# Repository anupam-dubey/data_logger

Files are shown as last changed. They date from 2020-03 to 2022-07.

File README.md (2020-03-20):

##  Data Logger with SD card and CSV Export    
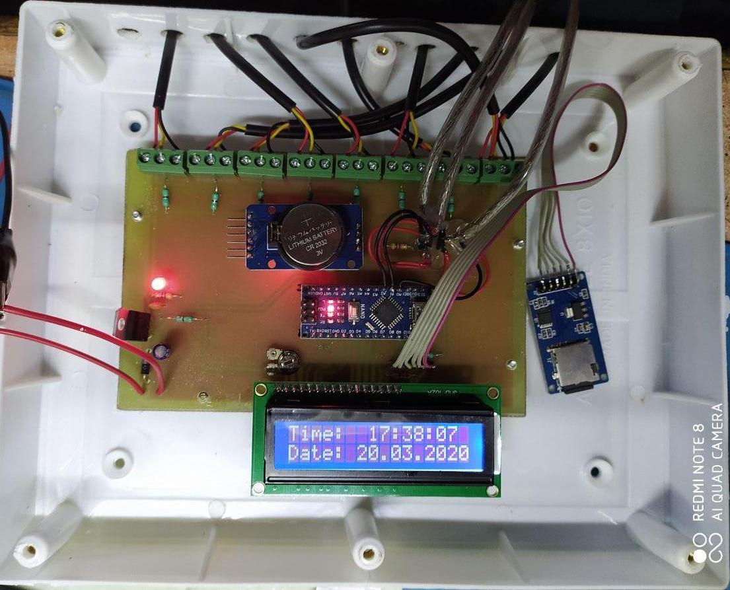
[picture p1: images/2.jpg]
           
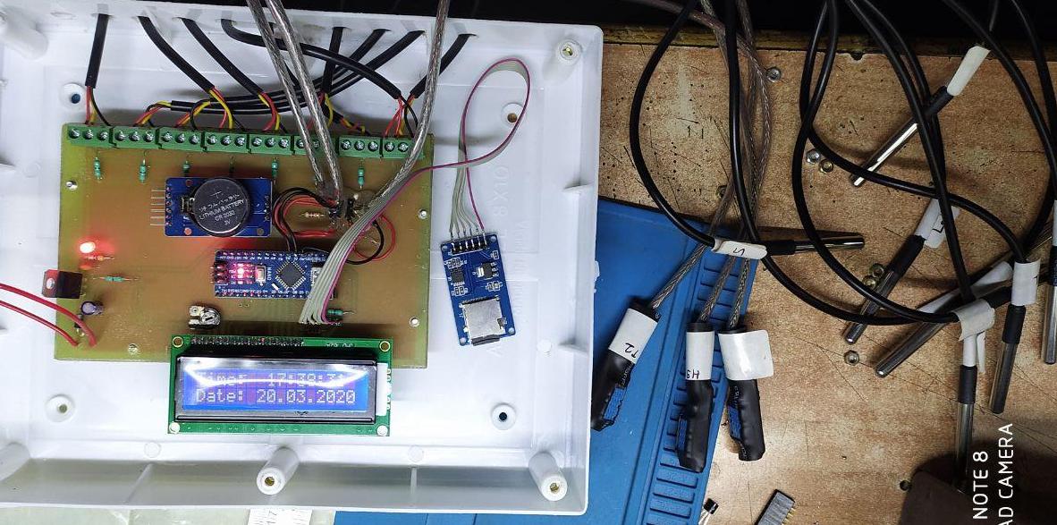
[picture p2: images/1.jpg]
     

#### Project reads data from 9 DS18b20 sensors   
#### alongwith 3 DHT11 sensor for 12 temperature readouts   
### HARDWARE   
Arduino nano ds3231 rtc module sd card module
Arduino ide is used with 16gb fat32 sd card  
project completed on 20/3/2020

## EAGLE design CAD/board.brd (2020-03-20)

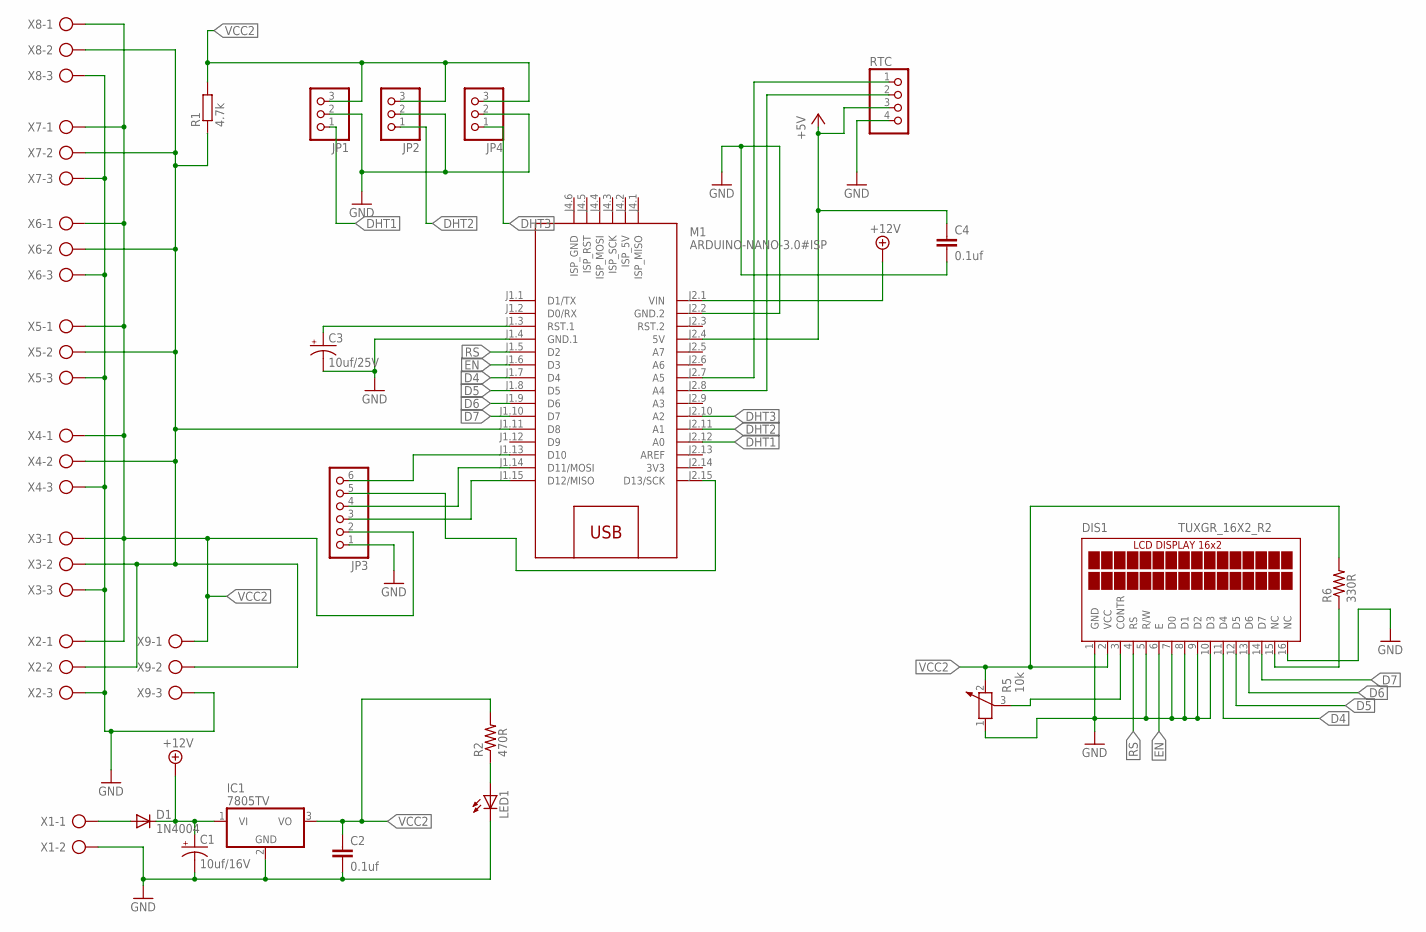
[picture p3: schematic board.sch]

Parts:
C1: 10uf/16V; E2,5-5
C2, C4: 0.1uf; C050-035X075
C3: 10uf/25V; E2,5-5
D1: 1N4004; DO41-10
DIS1: TUXGR_16X2_R2
IC1: 7805TV; TO220V
JP1, JP2, JP4: PINHD-1X3; 1X03
JP3: PINHD-1X6; 1X06
LED1: LED3MM
M1: ARDUINO-NANO-3.0#ISP
R1: 4.7k; 0207/10
R2: 470R; 0207/10@1
R5: 10k; PT-10
R6: 330R; 0207/10@1
RTC: PINHD-1X4; 1X04
X1: AK500/2
X2, X3, X4, X5, X6, X7, X8, X9: AK500/3

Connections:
3V3: M1.J2.14 (3V3)
+5V: C4.1, M1.J2.4 (5V), RTC.3
+12V: C1.+, D1.C, IC1.1 (VI), M1.J2.1 (VIN)
D4: DIS1.11 (D4), M1.J1.7 (D4)
D5: DIS1.12 (D5), M1.J1.8 (D5)
D6: DIS1.13 (D6), M1.J1.9 (D6)
D7: DIS1.14 (D7), M1.J1.10 (D7)
DHT1: JP1.1, M1.J2.12 (A0)
DHT2: JP2.1, M1.J2.11 (A1)
DHT3: JP4.1, M1.J2.10 (A2)
EN: DIS1.6 (E), M1.J1.6 (D3)
GND: C1.-, C2.2, C3.-, C4.2, DIS1.1 (GND), DIS1.5 (R/W), DIS1.7 (D0), DIS1.8 (D1), DIS1.9 (D2), DIS1.10 (D3), DIS1.16 (NC), IC1.2 (GND), JP1.2, JP2.2, JP3.1, JP4.2, LED1.K (C), M1.J1.4 (GND.1), M1.J2.2 (GND.2), R5.1, RTC.4, X1.2, X2.3, X3.3, X4.3, X5.3, X6.3, X7.3, X8.3, X9.3
unnamed: D1.A, X1.1
unnamed: C3.+, M1.J1.3 (RST.1)
unnamed: JP1.3, JP2.3, JP4.3, R1.2
unnamed: M1.J2.7 (A5), RTC.1
unnamed: M1.J2.8 (A4), RTC.2
unnamed: M1.J1.11 (D8), R1.1, X2.2, X3.2, X4.2, X5.2, X6.2, X7.2, X8.2, X9.2
unnamed: DIS1.3 (CONTR), R5.3
unnamed: DIS1.15 (NC), R6.1
unnamed: JP3.3, M1.J1.15 (D12/MISO)
unnamed: JP3.4, M1.J1.14 (D11/MOSI)
unnamed: JP3.5, M1.J2.15 (D13/SCK)
unnamed: JP3.6, M1.J1.13 (D10)
unnamed: LED1.A, R2.1
RS: DIS1.4 (RS), M1.J1.5 (D2)
VCC2: C2.1, DIS1.2 (VCC), IC1.3 (VO), JP3.2, R2.2, R5.2, R6.2, X2.1, X3.1, X4.1, X5.1, X6.1, X7.1, X8.1, X9.1

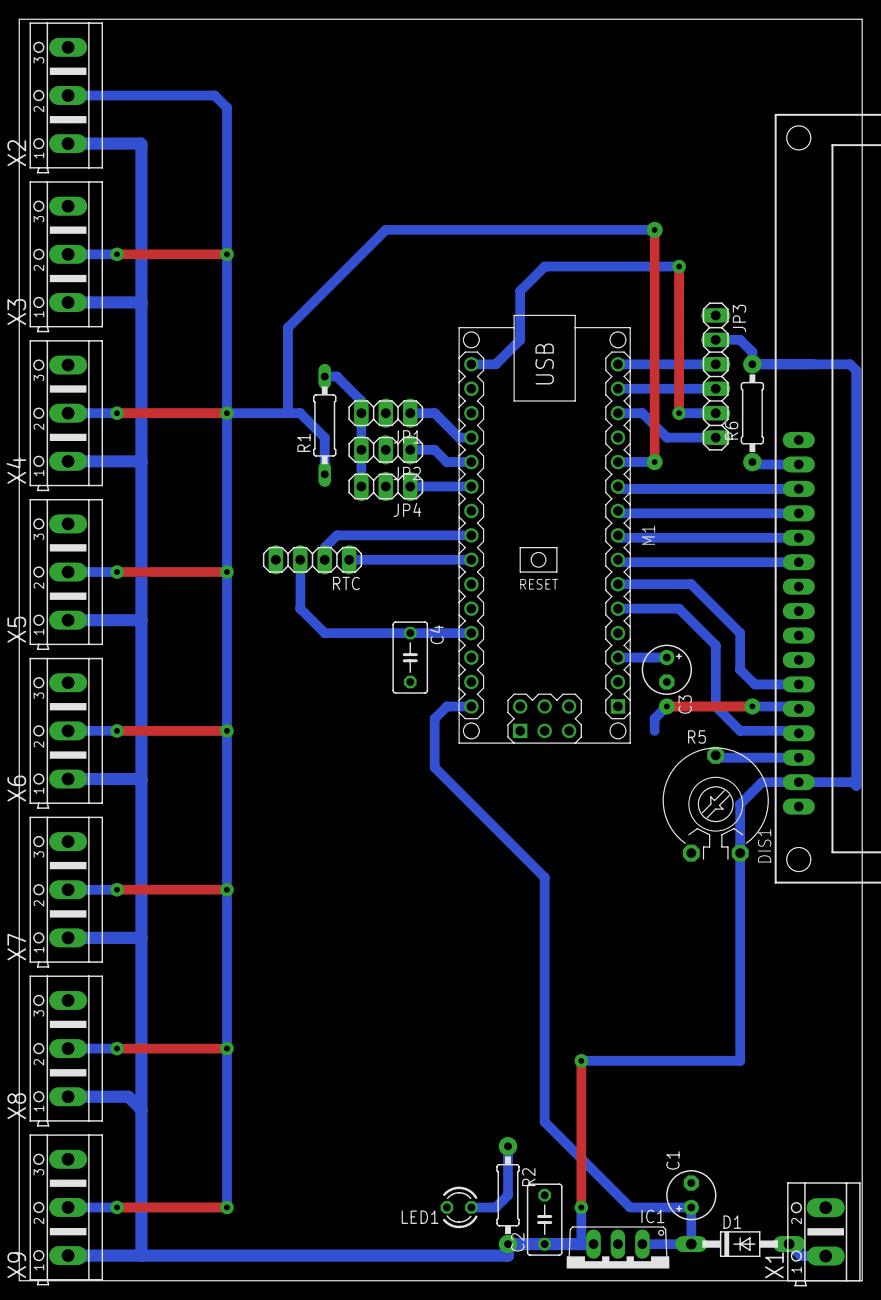
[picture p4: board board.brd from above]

Board: 2 copper layers, 87.6 x 131.1 mm, 27 parts (0 on the bottom side), 26 nets.

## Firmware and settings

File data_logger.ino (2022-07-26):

// just for ketan
#include <SPI.h>
#include <SD.h>
#include <DS3231.h>
#include <LiquidCrystal.h> // includes the LiquidCrystal Library 
#include <dht.h>
#include <OneWire.h>
#include <DallasTemperature.h>

#define dht1_pin A0
#define dht2_pin A1
#define dht3_pin A2

// Data wire is plugged into digital pin 2 on the Arduino
#define ONE_WIRE_BUS 8
int deviceCount = 0;
unsigned long interval=60000; // the time we need to wait
unsigned long previousMillis=0; // millis() returns an unsigned long.
// Setup a oneWire instance to communicate with any OneWire device
OneWire oneWire(ONE_WIRE_BUS);  

// Pass oneWire reference to DallasTemperature library
DallasTemperature sensors(&oneWire);

dht DHT1;
dht DHT2;
dht DHT3;
DS3231  rtc(SDA, SCL);
long id = 1;              //Store the id# of our reading
const int chipSelect = 10;
float t1,t2,t3,h1,h2,h3;
float temp[9];
LiquidCrystal lcd(2, 3, 4, 5, 6, 7); // Creates an LC object. Parameters: (rs, enable, d4, d5, d6, d7) 
void read_all_dht(void);
void read_all_temp(void);
void compress_save(void);
void setup() { 
  Serial.begin(115200);
 rtc.begin(); // Initialize the rtc object
 sensors.begin(); // Start up the library
 lcd.begin(16,2); // Initializes the interface to the LCD screen, and specifies the dimensions (width and height) of the display } 
//  rtc.setDOW(FRIDAY);     // Set Day-of-Week to SUNDAY
//  rtc.setTime(12, 58, 0);     // Set the time to 12:00:00 (24hr format)
//  rtc.setDate(20, 3, 2020);   // Set the date to January 1st, 2014
  pinMode(10, OUTPUT);
  delay(100);
   // see if the card is present and can be initialized:
  if (!SD.begin(chipSelect)) {
   // Serial.println("Card failed, or not present");
     lcd.setCursor(0,1);
     lcd.print("Card Fail");delay(1350);
    // don't do anything more:
    return;
  }
  lcd.setCursor(0,1);
  lcd.print("Card Success");delay(1350);
  //Write Log.csv File Header
  File logFile = SD.open("LOG.csv", FILE_WRITE);
  if (logFile)
  {
    logFile.println(", , , , , , , , , , , , , , , , ,"); //Just a leading blank line, incase there was previous data
    logFile.println("ID, Date, Time, T1, H1, T2, H2, T3, H3, T4, T5, T6, T7, T8, T9, T10, T11, T12");
    logFile.close();
  }
  read_all_dht();
  lcd.clear();
  delay(1000);
  lcd.print(t1,1);
  lcd.print(" ");
  lcd.print(t2,1);
  lcd.print(" ");
  lcd.print(t3,1);
  lcd.print(" ");
  lcd.setCursor(0,1);
  lcd.print(h1,1);
  lcd.print(" ");
  lcd.print(h2,1);
  lcd.print(" ");
  lcd.print(h3,1);
  lcd.print(" ");
  delay(2000);
  lcd.clear();
  deviceCount = sensors.getDeviceCount();
  lcd.print(deviceCount, DEC);
  lcd.setCursor(0,1);
  lcd.print("sensors. Found");
  delay(2000);
  lcd.clear();
}
void loop() { 
 unsigned long currentMillis = millis(); // grab current time
 
 // check if "interval" time has passed (1000 milliseconds)
 if ((unsigned long)(currentMillis - previousMillis) >= interval) {
  
   read_all_dht();
   read_all_temp();
   compress_save();
   // save the "current" time
   previousMillis = millis();
 }
 lcd.setCursor(0,0);
 lcd.print("Time:  ");
 lcd.print(rtc.getTimeStr());
 
 lcd.setCursor(0,1);
 lcd.print("Date: ");
 lcd.print(rtc.getDateStr());
  delay(1000); 
}
void read_all_dht()
{
  DHT1.read11(dht1_pin);
  DHT2.read11(dht2_pin);
  DHT3.read11(dht3_pin);
  h1=DHT1.humidity;
  t1=DHT1.temperature;
  h2=DHT2.humidity;
  t2=DHT2.temperature;
  h3=DHT3.humidity;
  t3=DHT3.temperature;
}
void read_all_temp()
{
 sensors.requestTemperatures(); 
  
  // Display temperature from each sensor
  lcd.clear();
  for (int i = 0;  i < deviceCount;  i++)
  { lcd.setCursor(0,0);
    lcd.print(i+1);
    lcd.print(" ");
    temp[i] = sensors.getTempCByIndex(i);
    lcd.print(temp[i],1);
    delay(500);
  }  
}
void compress_save()
{
   //Open a file to write to
  //Only one file can be open at a time
  String dataString = String(id) + ", " + rtc.getDateStr()+", " + rtc.getTimeStr() ;
  dataString += ", " + String(t1) + ", " + String(h1);
  dataString += ", " + String(t2) + ", " + String(h2);
  dataString += ", " + String(t3) + ", " + String(h3);
  dataString += ", " + String(temp[0]) + ", " + String(temp[1]);
  dataString += ", " + String(temp[2]) + ", " + String(temp[3]);
  dataString += ", " + String(temp[4]) + ", " + String(temp[5]);
  dataString += ", " + String(temp[6]) + ", " + String(temp[7]);
  dataString += ", " + String(temp[8]);
  Serial.println(dataString);
  File logFile = SD.open("LOG.csv", FILE_WRITE);
  if(logFile)
  {
    logFile.println(dataString);
    logFile.close();
  //  Serial.println(dataString);
  }
}

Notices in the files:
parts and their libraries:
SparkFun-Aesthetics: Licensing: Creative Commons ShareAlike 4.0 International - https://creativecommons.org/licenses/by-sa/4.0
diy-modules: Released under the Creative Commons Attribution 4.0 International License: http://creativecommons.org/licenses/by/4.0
